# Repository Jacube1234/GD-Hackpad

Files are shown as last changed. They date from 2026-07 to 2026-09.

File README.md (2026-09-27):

# GD Hackpad


<br>
View PCB on KiCanvas

<a href="https://youtu.be/eFOGvQzMtF8">
  Video Demo
</a>
<br>
talking about design
<br>
<br>
<a href="https://youtu.be/FZbB-Cm0QQ0">
  Talking About Design
</a>
<br>
video demo
<br>
<br>
<br>

<p align="center">
  <!-- Tall Photos Row -->
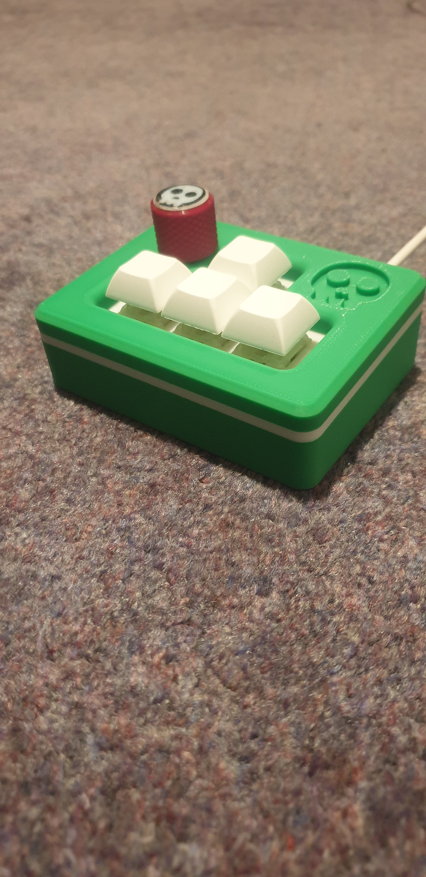
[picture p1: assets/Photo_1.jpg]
Hackpad Top Angle
  
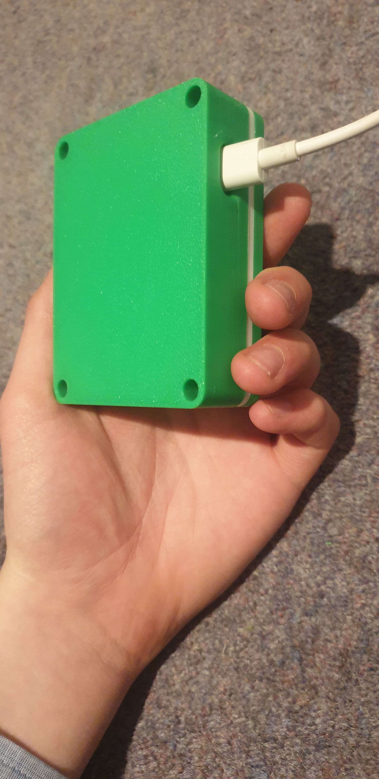
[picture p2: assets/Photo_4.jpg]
Hackpad Base and USB Cable
  
</p>
<p align="center">
  <!-- Wide Photos Row -->
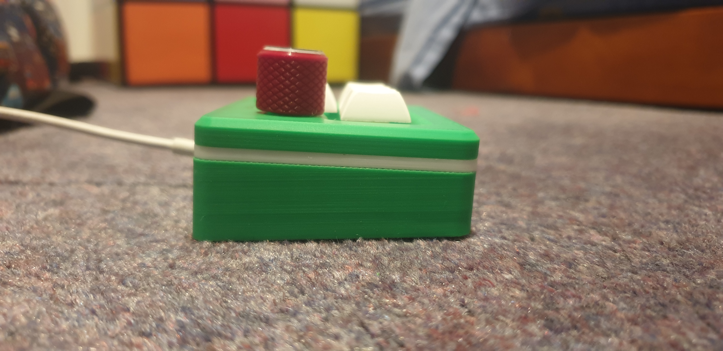
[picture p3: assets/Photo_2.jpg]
Hackpad Side Profile
  
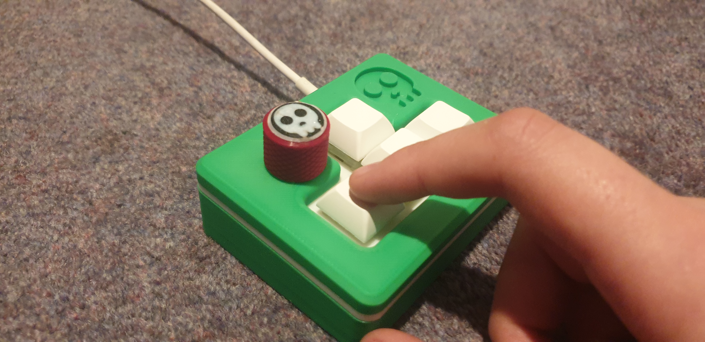
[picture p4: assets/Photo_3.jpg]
Hackpad in Use
  
</p>
<br>

**Note on images and files:** The photos and physical build shown below do not have the RGB LEDs or don't have them working due to a footprint error on my design. However, the **updated KiCad and Gerber files in this repository include the corrected LED routing**, so if you fabricate a board using the current files, the LEDs will work fully as designed!

This is my Hackpad designed for the purpose to play Geometry Dash Platformer levels. Basically a DIY Sayo Device but cool yk. 
I chose this project as I am comfortable with Fusion 360, and a chance to learn a new program - Kicad.

## Features:
- Cool 3d printed case
- 2 WS2812B RGB LEDs. Kinda under the keys. I just didn't want it to be too basic. Can also tell me whether its powered on.
- 4 arrow keys to play games
- Rotary encoder

## CAD Model:
Everything fits together using 4 M3 Bolts and heatset inserts. 4 for the case.

It has 3 separate printed pieces. The base which has a tilt, the plate to hold the PCB, and the top shell.

Made in Fusion360.

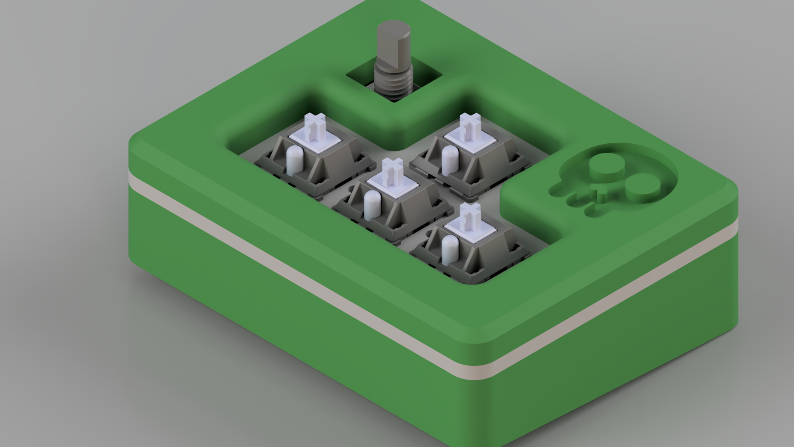
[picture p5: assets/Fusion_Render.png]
Fusion 360 Render


I added these elevated holes because the shell was 3mm tall, which is shorter than the depth needed for the heatset inserts. Still looks visually fine I reckon.

This also shows how it is assembled. The top plate and angled base sandwhich the plate the holds the switches.
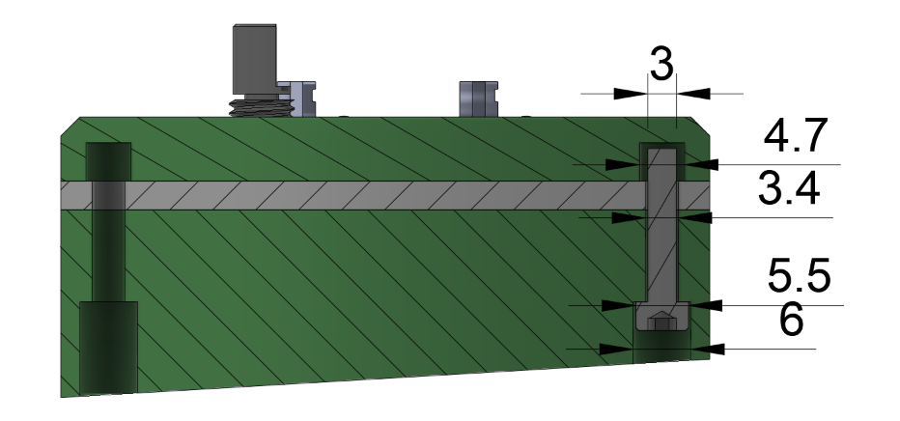
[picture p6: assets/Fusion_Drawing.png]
Fusion_Drawing


## PCB
Here's my PCB!💀 It was made in KiCad. I added the silkscreen image by using the build in image converter.
I got a skull emoji off google, and placed it on my front silkscreen layer.

Schematic

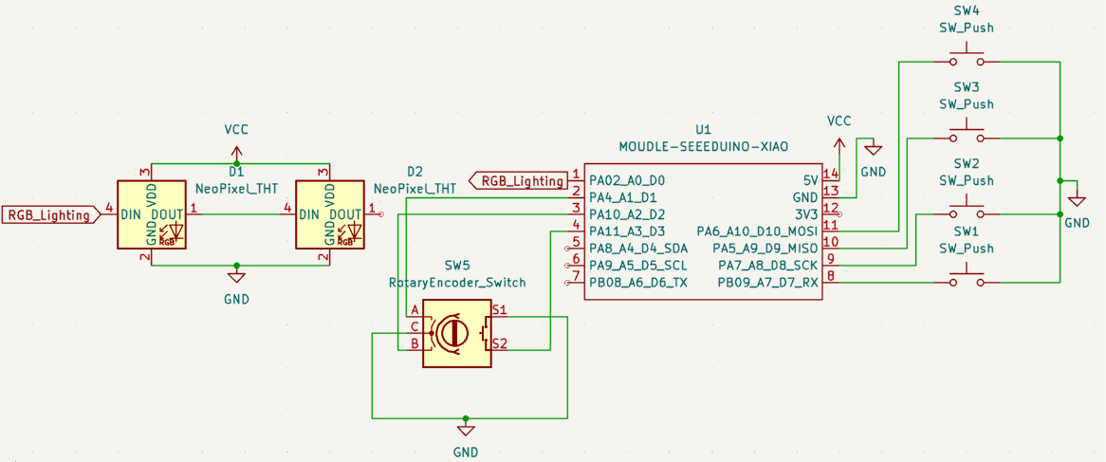
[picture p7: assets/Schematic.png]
Schematic


Layout

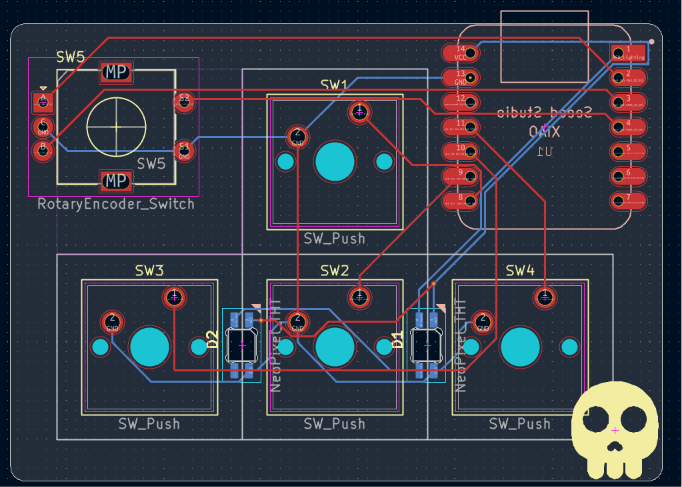
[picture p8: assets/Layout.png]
Layout of PCB


PCB

3D Viewer

## Firmware Overview
This hackpad uses KMK firmware for everything.

I might change the lights to change colour in the future.

## File structure

There's 4 main folders: CAD, Firmware, PCB, and Production. The CAD folder contains the .step file for the case as a whole. It also contains the 3mf of the same thing, and the fusion f3z. The PCB folder contains .kicad_pcb, .kicad_pro, and .kicad_sch. The Firmware folder contains files for KMK firmware. The production folder has files for 3D printing and for the PCB printing.

## BOM (Bill of Materials):
Here should be everything you need to make this hackpad

- 1 Unsoldered Seeed XIAO RP2040
- 4x MX-Style switches
- 4x white blank DSA keycaps
- 2x SK6812 MINI-E LEDs (Neopixels)
- 1x EC11E Rotary Encoder
- 4x M3x16mm screws
- 4x M3x5mx4mm heatset inserts
- 3D printed case
- 3D printed knob
- PCB

## Software

- KMK folder from [here](https://github.com/KMKfw/kmk_firmware/blob/main/docs/en/Getting_Started.md) and have a quick read through. Download where it says "copy of KMK" or [here](https://github.com/KMKfw/kmk_firmware/archive/refs/heads/main.zip)
- UF2 Circuit python [for the Seeed XIAO RP2040](https://circuitpython.org/board/seeeduino_xiao_rp2040/)
- Fusion is recommended if you want to look through my building timeline [here](https://github.com/Jacube1234/GD-Hackpad/blob/main/CAD/Final/Hackpad.f3z)
- Kicad recommended to view the Gerber files or the general `.pcb` `.pro` `.sch` files
## Tools:

- 3D Printer
- Soldering Iron
- Solder
- M3 Allen key

## How to build/replicate
1. Get **everything** that is on the BOM.

- Download the step files from [here](https://github.com/Jacube1234/GD-Hackpad/tree/main/Production) and 3d print them.
- Use the Gerber files [here](https://github.com/Jacube1234/GD-Hackpad/tree/main/Production) to order the pcb online.
- Buy the screws and heatset inserts online or at a hardware store.
- Buy the rest of the items online somewhere (sorry!)

Note that I will be getting most parts from Alex's Hackpad kit, and and the pcb ordered with the $15 grant.

2. **Solder** the parts **but *NOT* the switches** in their specificed location using solder and a soldering iron.
- If you need help refer to the images earlier in this `README.md` or [here](https://github.com/Jacube1234/GD-Hackpad/tree/main/assets)

3. **Install the heat-set inserts.** Heat up your soldering iron and gently press the 4 M3 heat-set inserts into the 3D printed case. Take your time and let the heat do the work so you don't accidentally melt all the way through the plastic.

4. **Put the software on the XIAO RP2040.** Plug the microcontroller into your computer and drop the CircuitPython `.uf2` file from [here](https://circuitpython.org/board/seeeduino_xiao_rp2040/) onto the `RPI-RP2` drive. Basically follow [this](https://github.com/KMKfw/kmk_firmware/blob/main/docs/en/Getting_Started.md)

5. **Install KMK and your code.** Put the `kmk` folder from the KMK firmware zip and the files from the `Firmware` folder in this repository onto the new `CIRCUITPY` drive.

6. **Assemble the hardware.** Snap your 4 MX switches through the 3D-printed plate so they sit securely. Sandwich your finished PCB between the base piece and the top shell, making sure the plate is aligned correctly. 

7. **Screw it together.** Thread your 4 M3x16mm screws through the bottom of the case and into the heat-set inserts you installed in step 3. Try not to overtighten them.

8. **Finishing touches.** Slap your 4 blank white DSA keycaps onto the switches and push the custom 3D-printed knob onto the rotary encoder.

Hopefully it should work flawlessly because I have 100% tested the code.

## Project Reflection
Some stuff already mentioned elsewhere in this `README.md`
- **What I made:** I made the GD Hackpad—a custom 4-key macro pad with a rotary encoder designed specifically for playing Geometry Dash Platformer levels (basically a DIY Sayo Device). It features a 3-piece 3D-printed angled case designed in Fusion 360, a custom PCB featuring a skull silkscreen created in KiCad, and is powered by a Seeed XIAO RP2040 running KMK firmware.
- **What was challenging:** Learning KiCad from scratch since I was originally much more comfortable with Fusion 360. Learning the stardance process and this general hackclub stuff.
- **What I am proud of:** How well the 3D-printed case fits together using M3 bolts and heat-set inserts, adding a custom skull emoji silkscreen to the PCB, and getting everything running smoothly with 100% tested code.
- **How to test:** Everything you need to replicate it is in the repository, including the 3D print production files, Gerber files for ordering the PCB, the BOM, and a full guide on setting up CircuitPython and KMK firmware. Note: The photos of my physical build ldon’t have the RGB LEDs due to an early board error, but the updated KiCad and Gerber files in the repo feature the corrected LED routing!

## Extra stuff
Hi guys

Bye guys

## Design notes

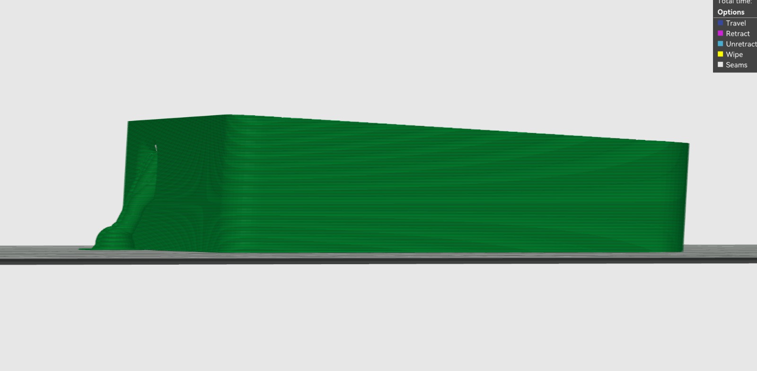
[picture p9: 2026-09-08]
assets/IMG-20260902-WA0003.jpg

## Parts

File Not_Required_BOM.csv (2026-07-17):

Item Name | Qty | Notes
Seeed XIAO RP2040 | 1 | Unsoldered
MX-Style switches | 4
White blank DSA keycaps | 4
SK6812 MINI-E LEDs | 2 | Neopixels
EC11E Rotary Encoder | 1
M3x16mm screws | 4
M3x5mm x 4mm heatset inserts | 4
3D printed case | 1 | Printed from CAD files
3D printed knob | 1 | Printed from CAD files
PCB | 1 | Ordered via Gerber files

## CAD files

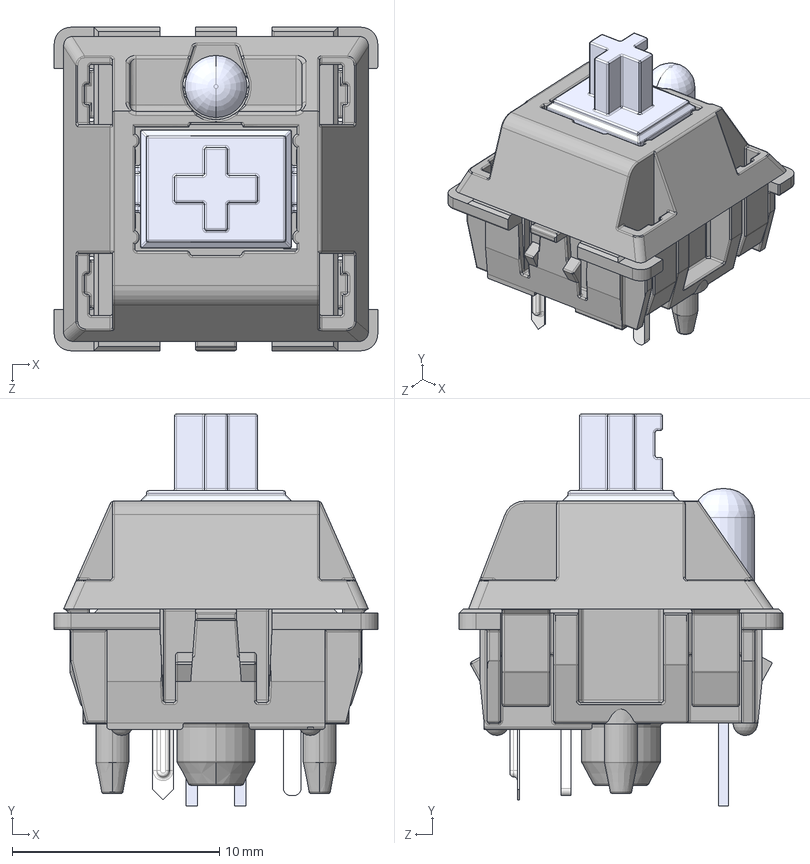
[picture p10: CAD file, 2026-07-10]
assets/Components/MX.STEP
15.6 x 18.9 x 15.6 mm
MX 轴 按键′_ü___¨1
MX 轴 轴体áì_¨￠¨__
MX粣 拸簽LEDLEDLED
MX轴 轴体 底部 μ×2__默认_á2____è_
针脚___默认__è_

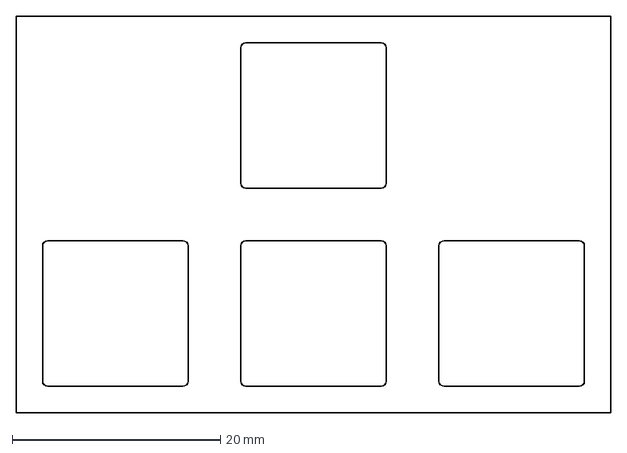
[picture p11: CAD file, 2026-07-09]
assets/Key_Layout.dxf
57.1 x 38.1 mm

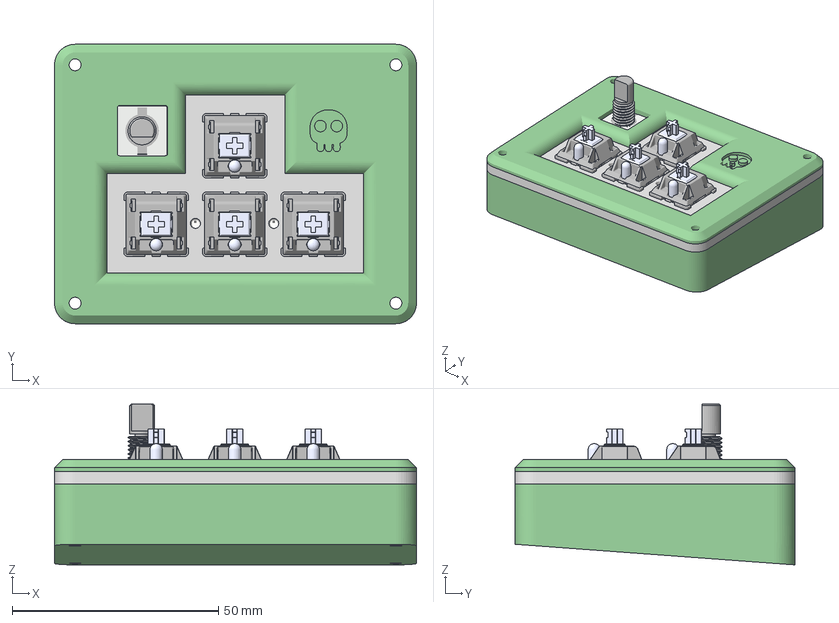
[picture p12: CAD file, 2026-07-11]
CAD/Final/Hackpad.3mf
87.8 x 67.8 x 39.0 mm
Base
Plate

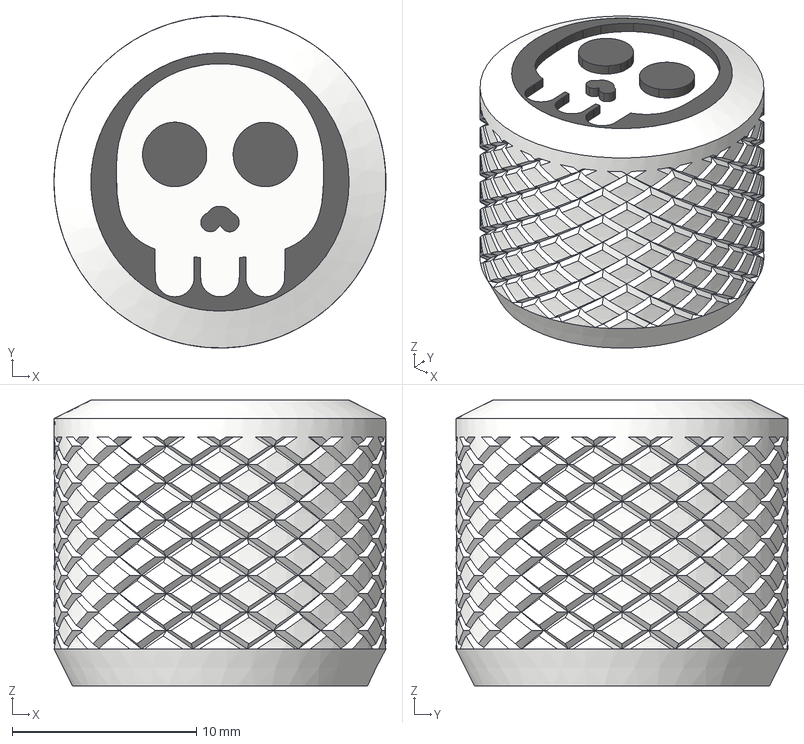
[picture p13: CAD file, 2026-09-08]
Production/Skull knob.step
18.0 x 18.0 x 15.5 mm
Base
Skull

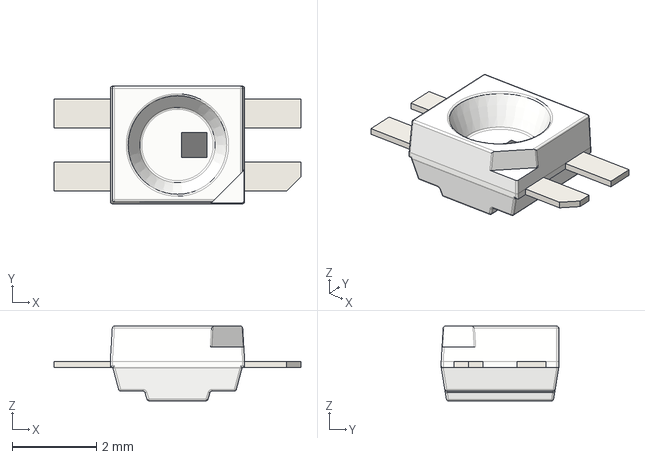
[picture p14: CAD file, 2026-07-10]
assets/Components/LED_SK6812MINI-E.step
5.88 x 2.80 x 1.78 mm

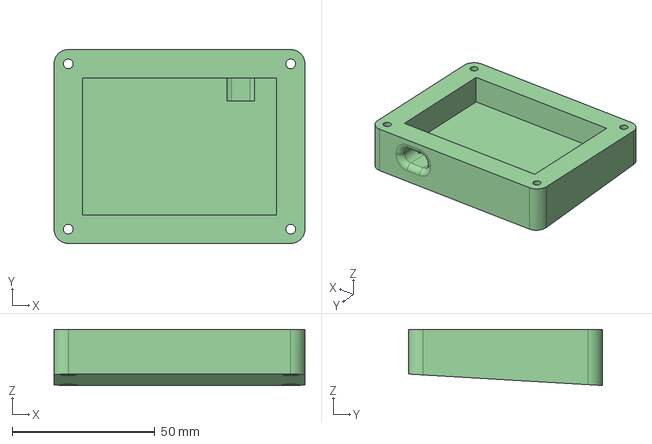
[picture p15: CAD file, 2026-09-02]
Production/Base realistic port location.step
87.8 x 67.8 x 19.6 mm

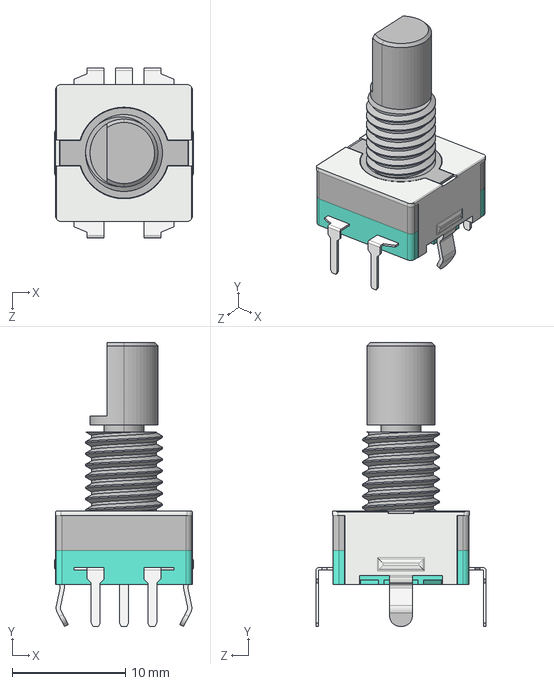
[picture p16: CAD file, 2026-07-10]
assets/Components/EC11_Rotary_Encoder_Switched.step
12.3 x 25.1 x 15.0 mm

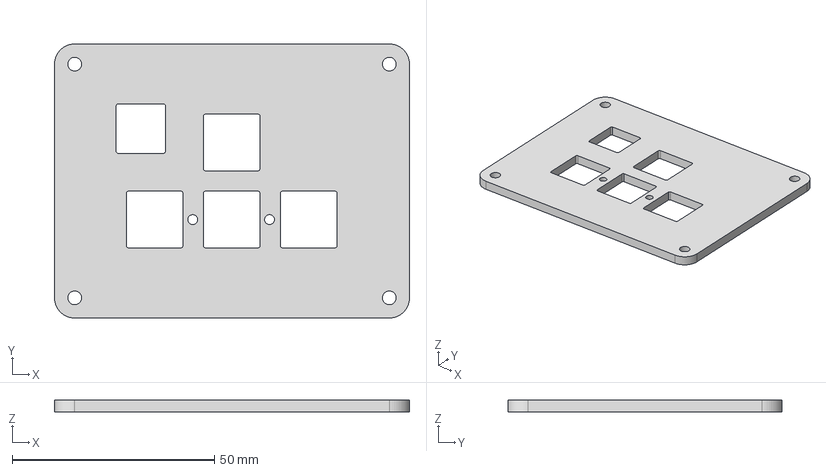
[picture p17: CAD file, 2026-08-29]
Production/Plate.step
87.8 x 67.8 x 3.00 mm

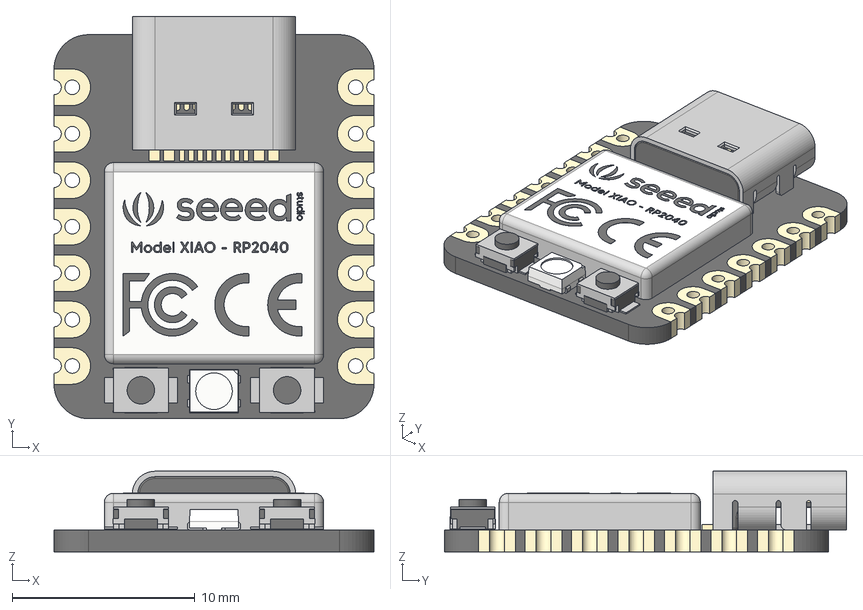
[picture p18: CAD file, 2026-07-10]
assets/Components/Seeed Studio XIAO RP2040 v26.step
17.5 x 22.0 x 4.40 mm
type-c v2
smd_button v3
DOUT
DIN
VSS
VDD
smd_button v3(Mirror)

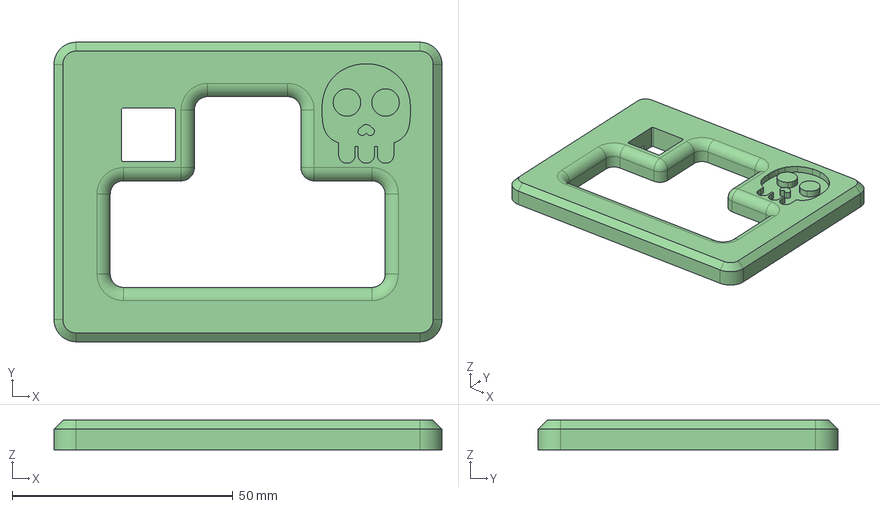
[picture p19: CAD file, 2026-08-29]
Production/Shell.step
87.8 x 67.8 x 6.70 mm

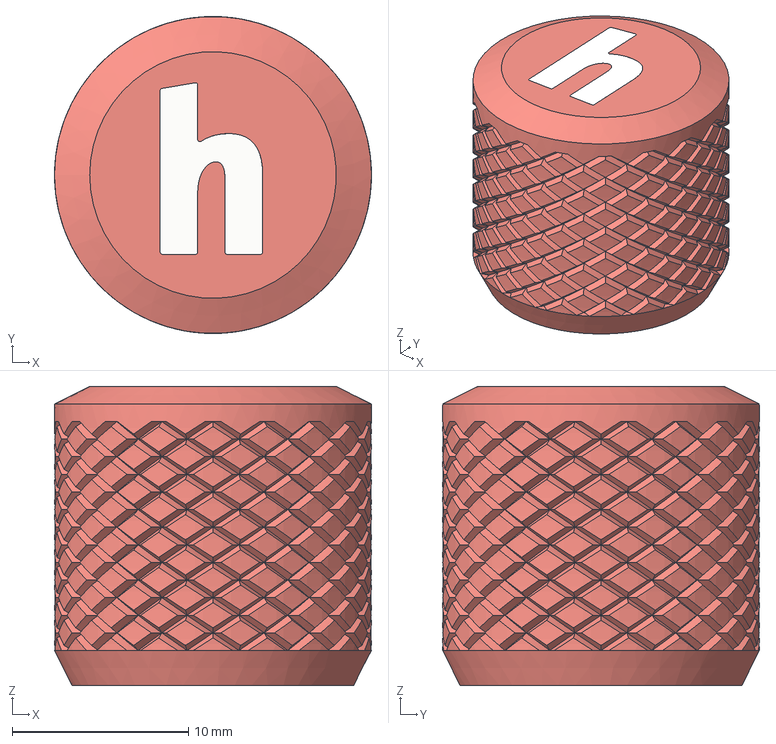
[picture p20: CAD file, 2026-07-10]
assets/Components/Hack Club Knurled Knob.step
18.0 x 18.0 x 17.0 mm
Base
H

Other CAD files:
Production/Base.step
CAD/Final/Hackpad.f3z

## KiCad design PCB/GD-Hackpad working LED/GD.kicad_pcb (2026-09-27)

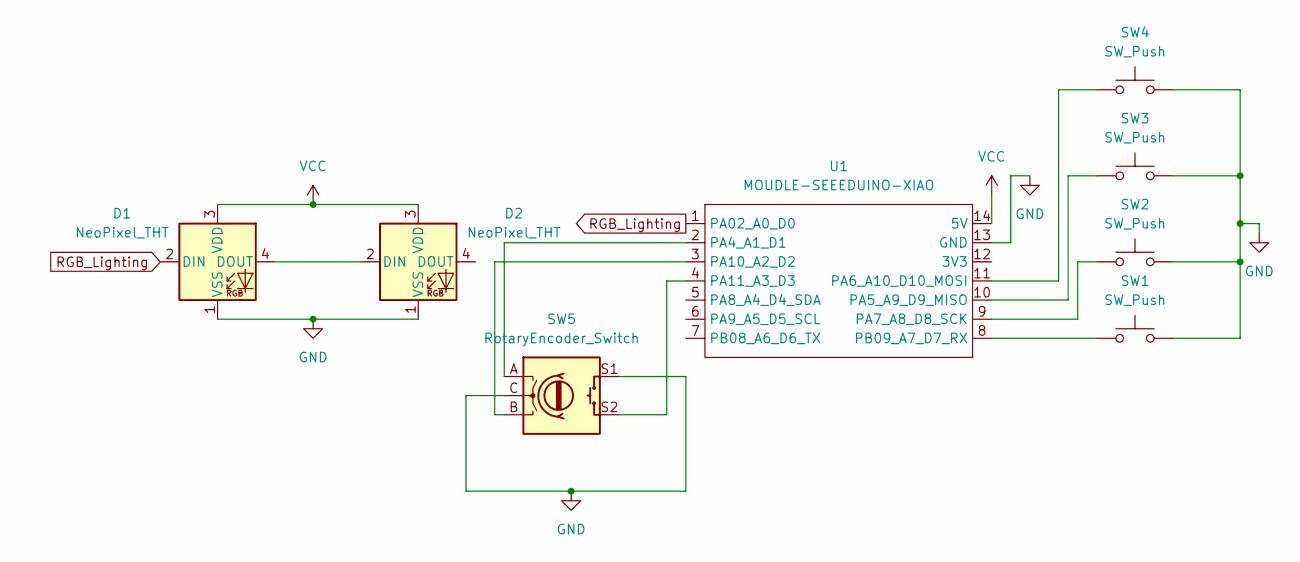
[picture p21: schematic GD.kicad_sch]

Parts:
D1, D2: NeoPixel_THT; LED_SK6812MINI-E_3.2x2.8mm_P1.5mm_ReverseMount
SW1, SW2, SW3, SW4: SW_Push; SW_Cherry_MX_1.00u_PCB
SW5: RotaryEncoder_Switch; RotaryEncoder_Alps_EC11E-Switch_Vertical_H20mm
U1: MOUDLE-SEEEDUINO-XIAO; XIAO-Generic-Hybrid-14P-2.54-21X17.8MM

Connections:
GND: D1.1 (VSS), D2.1 (VSS), SW1.2, SW2.2, SW3.2, SW4.2, SW5.C, SW5.S1, U1.13 (GND)
unnamed: D1.4 (DOUT), D2.2 (DIN)
unnamed: SW5.A, U1.2 (PA4_A1_D1)
unnamed: SW3.1, U1.10 (PA5_A9_D9_MISO)
unnamed: SW4.1, U1.11 (PA6_A10_D10_MOSI)
unnamed: SW2.1, U1.9 (PA7_A8_D8_SCK)
unnamed: SW5.B, U1.3 (PA10_A2_D2)
unnamed: SW5.S2, U1.4 (PA11_A3_D3)
unnamed: SW1.1, U1.8 (PB09_A7_D7_RX)
RGB_Lighting: D1.2 (DIN), U1.1 (PA02_A0_D0)
VCC: D1.3 (VDD), D2.3 (VDD), U1.14 (5V)

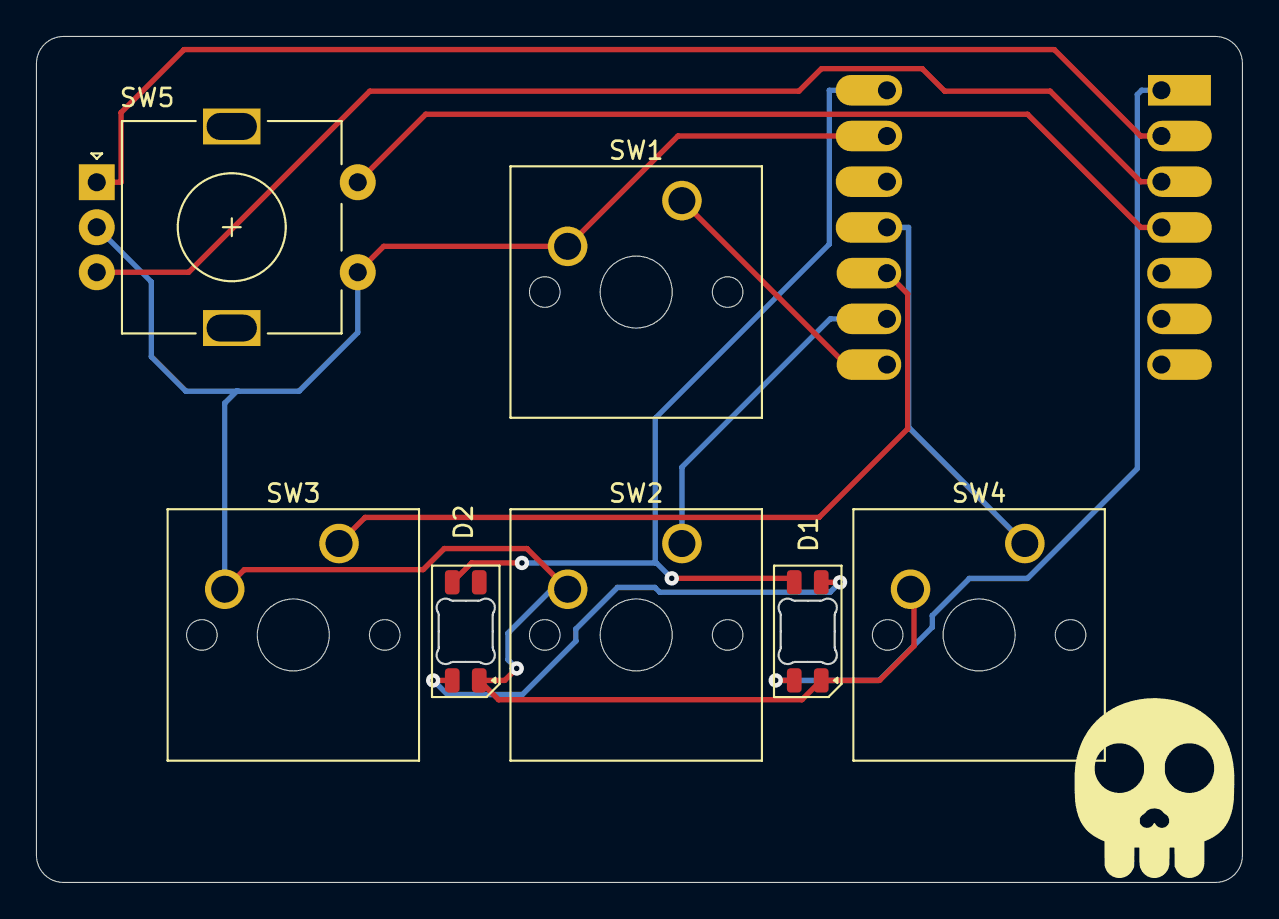
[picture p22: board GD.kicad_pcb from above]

Board: 2 copper layers, 67.0 x 47.0 mm, 8 parts (1 on the bottom side), 11 nets.

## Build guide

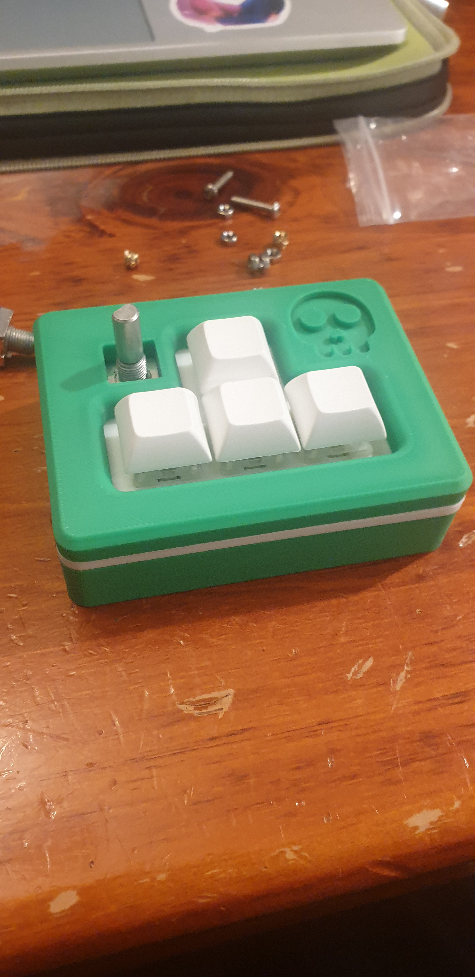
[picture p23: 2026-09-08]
assets/Assembly.jpg

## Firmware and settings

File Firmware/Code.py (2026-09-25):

print("Starting")

import board
from kmk.kmk_keyboard import KMKKeyboard
from kmk.keys import KC
from kmk.scanners.keypad import KeysScanner
from kmk.modules.encoder import EncoderHandler
from kmk.extensions.media_keys import MediaKeys

keyboard = KMKKeyboard()

# 1. Enable Media Keys for volume control
keyboard.extensions.append(MediaKeys())

# 2. Rotary Encoder setup (Rotation on D1 & D2)
encoder_handler = EncoderHandler()
encoder_handler.pins = ((board.D1, board.D2),)
encoder_handler.map = [
    ((KC.AUDIO_VOL_UP, KC.AUDIO_VOL_DOWN),)
]
keyboard.modules.append(encoder_handler)

# 3. Matrix Scanner: WASD/Arrows (D7, D8, D9, D10) + Encoder Click (D3)
keyboard.matrix = KeysScanner(
    pins=[board.D7, board.D8, board.D9, board.D10, board.D3],
    value_when_pressed=False,
    pull=True,
)

# 4. Keymap: Arrow keys + Mute on encoder click
keyboard.keymap = [
    [KC.UP, KC.DOWN, KC.LEFT, KC.RIGHT, KC.MUTE]
]

if __name__ == '__main__':
    keyboard.go()

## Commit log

2026-07-09 Add README.md for Hackpad project
    Added detailed project description, features, CAD model, PCB information, firmware overview, and BOM for the hackpad.
2026-07-09 Add images to assets
    To use in README.md
    [plate-2026-07-08T20_49_49.746Z.dxf]
2026-07-09 Renamed .dxf file and moved to folder
    [Key_Layout.dxf]
2026-07-09 Add Fusion 360 render image to README
    Add a rendered image of the Fusion 360 design to the README documentation to visually showcase the 3D printed device.
2026-07-09 Replaced images
    Changed PCB images of the fixed LED version
2026-07-09 Sort files. Added .gitignore
    title^ Moved Kicad stuff inside the actual project
    [Hackpad schematic.kicad_pcb, Hackpad schematic.kicad_sch, Hackpad.3mf]
2026-07-10 Added rotary knob
    Added rotary knob. Made skull smaller
    [Hackpad schematic.kicad_pcb, Hackpad schematic.kicad_sch]
2026-07-10 Add rotary encoder (SW6) and reorganize PCB layout
    Added a new Alps EC11E rotary encoder (SW6) to the PCB at position (1.525, 4.625). Repositioned existing rotary encoder (SW5) and the logo footprint. Updated PCB traces and routing to accommodate the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
    [Hackpad schematic.kicad_pcb]
2026-07-10 Added knob
    [Hack Club Knurled Knob.step, Hackpad.f3d]
2026-07-10 Flipped microcontroller
    Flipped microcontroller. Updated images and 3d model. Added KMK library
    [EC11_Rotary_Encoder_Switched.step, Hackpad schematic.kicad_pcb, Hackpad.3mf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]
2026-07-11 new file: CAD/Final/Hackpad.3mf new file: CAD/Final/Hackpad.f3z new file: CAD/Final/Hackpad.step deleted: CAD/Hackpad.3mf deleted: CAD/Hackpad.f3d renamed: CAD/PCB.step -> CAD/PCB/PCB.step modified: 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
    [EC11_Rotary_Encoder_Switched.step, Hack Club Knurled Knob.step, Hackpad.3mf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]
2026-07-11 modified: PCB/Hackpad schematic.kicad_pcb
    [Hackpad schematic.kicad_pcb]
2026-07-11 Added Gerber files.
    Added Gerber files. Updated README.md
2026-07-11 Add rotary encoder feature and CAD details
    Added rotary encoder to feature list and documented the elevated holes design decision for heatset inserts. Included new technical drawing image to illustrate the design solution.
2026-07-11 Made fusion bodies into components.
    Updated CAD folder
    [Base.step, Plate.step, Shell.step]
2026-07-12 Add build guide and changed .gitignore
    Added step-by-step assembly instructions, software setup section with KMK and CircuitPython details, and clarified BOM terminology. Updated .gitignore to exclude KMK folders and UF2 files. This makes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
2026-07-17 Added non required BOM in .csv
    [Not_Required_BOM.csv]
2026-08-27 Updated case
    [Base.step, Hackpad.f3z, Shell.step]
2026-08-29 Updated model
    [Base.step, Hackpad.f3z, Plate.step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]
2026-08-31 Changed pin numbers to be correct
    [Code.py]
2026-09-01 Added working code for keys and mute for encoder.
2026-09-01 Create realistic location based off my real world port location
    [Hackpad realistic port location.step]
2026-09-01 Renamed file
    [Base realistic port location.step]
2026-09-02 updated again. did the wrong file smh
    [Base realistic port location.step]
2026-09-08 Added more assets
    [Skull knob.step]
2026-09-25 Working code for keys and encoder no RBG
2026-09-27 Working LED Gerbers
    [Hackpad schematic.kicad_pcb, Hackpad schematic.kicad_sch]
2026-09-27 Separate kicad files for LED version
    [GD.kicad_pcb, GD.kicad_sch, Hackpad schematic.kicad_pcb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]
2026-09-27 Added other video and led disclaimer thing
